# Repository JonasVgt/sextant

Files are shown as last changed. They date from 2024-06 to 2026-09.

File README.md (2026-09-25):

# 3D-Printed Sextant

## What is a sextant?
A sextant is a navigational instrument used for measuring
the angular distances between two objects, such as the 
horizon and a celestial body like the sun or a star. Using
these angles, navigators can determine their latitude 
and longitude. The accuracy and portability of the sextant
made it an essential tool for ocean navigation in the age of 
sail. Nowadays sextants are mostly used by hobbyists and as
a reliable backup to modern GPS technology.

## This Project

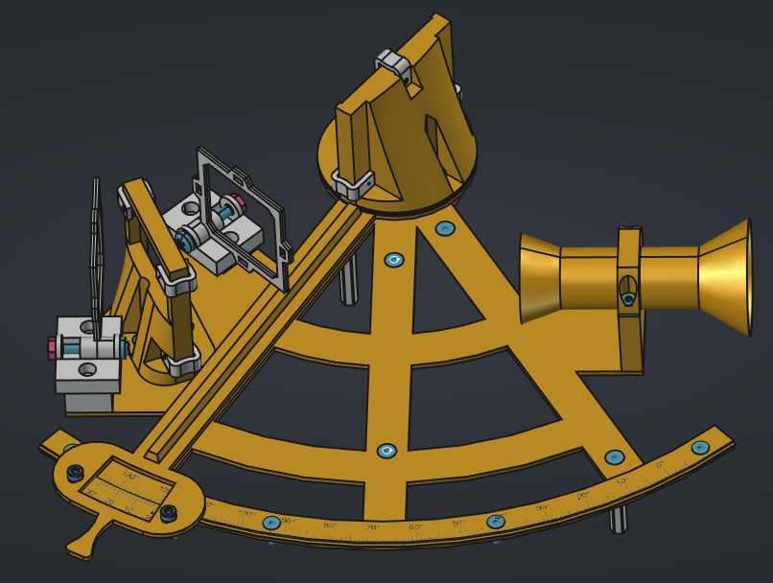
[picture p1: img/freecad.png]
FreeCAD preview of the sextant


After being caught in a rabbit hole of astronavigation, I 
wanted to experiment with navigation using sextants. 
Unfortunately, I quickly found  out that these devices are 
really expensive, and I didn't want to spend hundreds of 
dollars on my first sextant. That is why I decided to build 
my own, using 3D printing technology. The main focus of this 
project is to create a very cheap sextant that can be used 
by everyone who wants to experiment with astronavigation. I 
will try to make the device as accurate as possible, with a 
theoretical accuracy of around 1/6th of a degree or 10 nautical 
miles. For more accurate measurements, different techniques 
and materials are probably needed. The design will be 
modular, so everyone can change it to fit their needs.

## Building your own
### What do you need?
You will need the following materials:

| Amount | Description |
| - | - |
| 10 | M3x10 Bolt (flat head) |
| 3 | M3x8 Bolt (countersunk head) |
| 6 | M3x10 Bolt (countersunk head) |
| 15 | M3 Hex Nut |
| 1 | M3x16 Bolt (countersunk head) |
| 2 | M4x20 Bolt (flat head) |
| 2 | M4 Hex Nut |
| 4 | M3x5 Bolt (countersunk) |
| 4 | M3x35 Hex standoff |
| 2 | Mirror 50x40x3mm |
| 1 | 608-ZZ Ball Bearing |
|  | Filament |

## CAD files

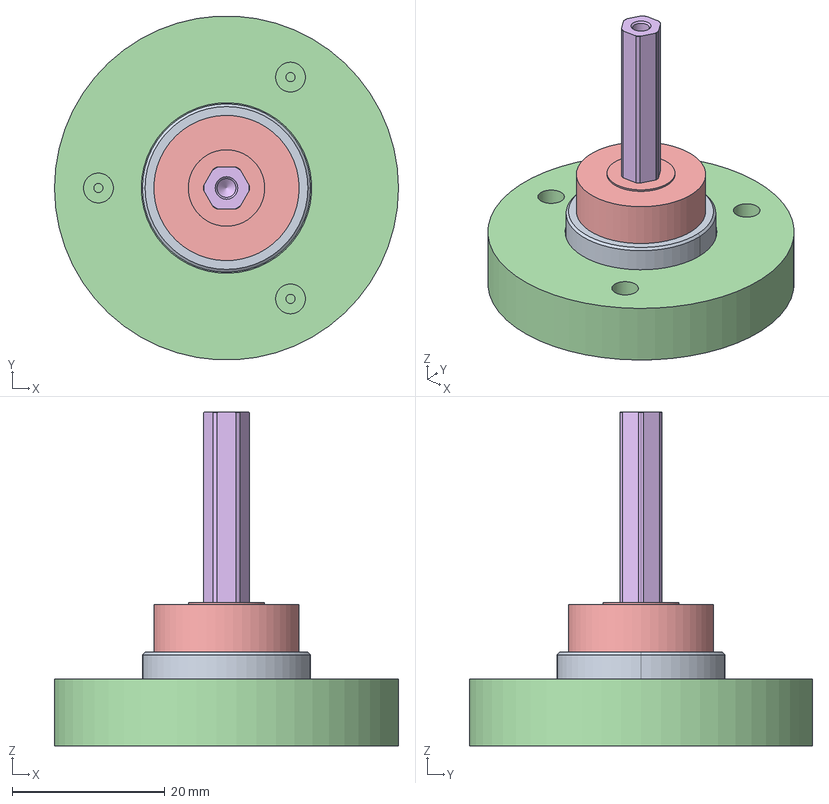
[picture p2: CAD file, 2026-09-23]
FreeCAD/Parts.FCStd
45.0 x 44.9 x 43.7 mm
6661K82_Ball Bearing
6661K82_Ball Bearing001
6661K82_Ball Bearing002
6661K82_Ball Bearing003
6661K82_Ball Bearing004
6661K82_Ball Bearing005
6661K82_Ball Bearing006
6661K82_Ball Bearing007
6661K82_Ball Bearing008
6661K82_Ball Bearing009
6661K82_Ball Bearing010
6661K82_Ball Bearing011
6661K82_Ball Bearing012
6661K82_Ball Bearing013
6661K82_Ball Bearing014
6661K82_Ball Bearing015
6661K82_Ball Bearing016
6661K82_Ball Bearing017
MirrorClipBody
BearingHousingBody
M3x35x5.5-Spacer

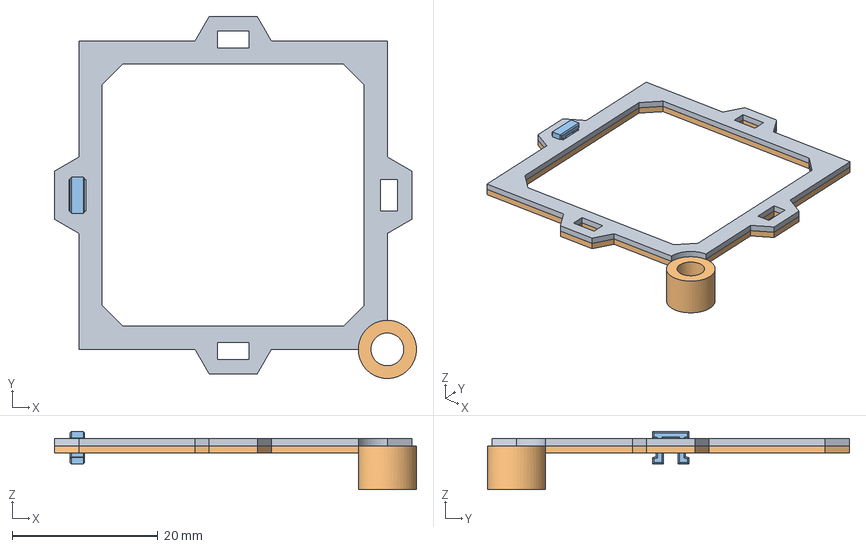
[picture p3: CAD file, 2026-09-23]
FreeCAD/Shade.FCStd
49.7 x 49.7 x 8.00 mm
ShadeFrameTop
ShadeFrameBottom
Clip

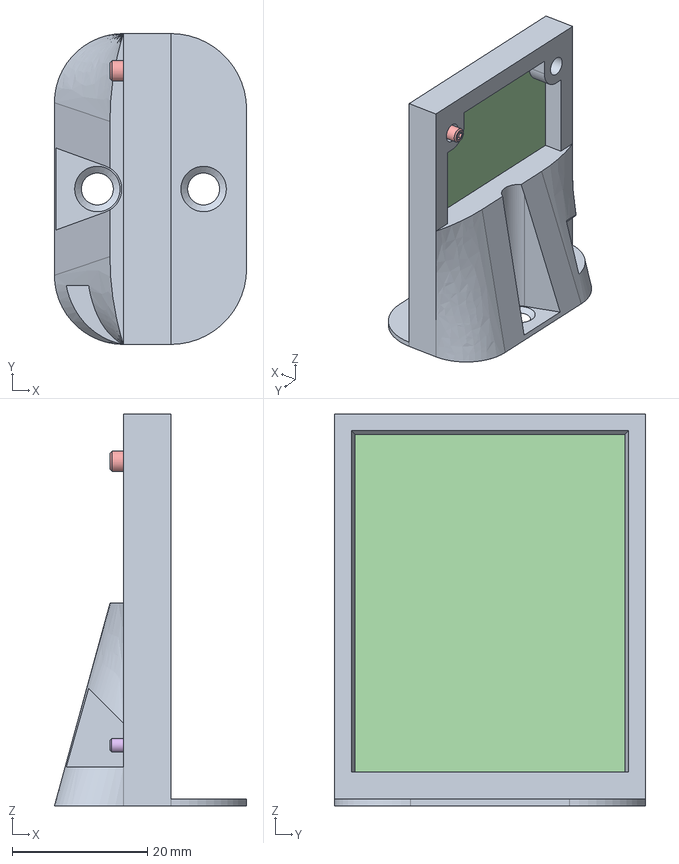
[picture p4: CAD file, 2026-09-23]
FreeCAD/HorizonMirror.FCStd
28.4 x 46.0 x 58.0 mm
HorizonMirrorFrameBody
Binder
M3x4-Screw
M2x4-Screw

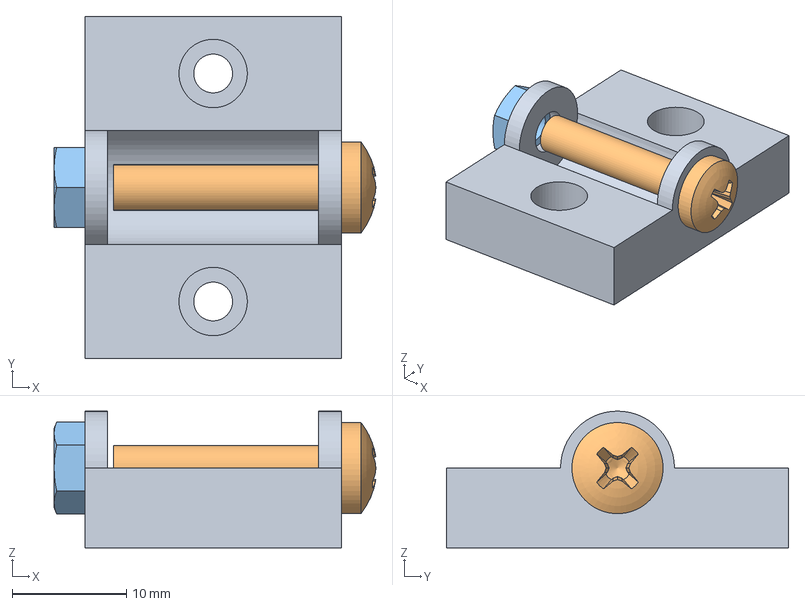
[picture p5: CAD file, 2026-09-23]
FreeCAD/Shadeset.FCStd
28.2 x 30.0 x 12.0 mm
Attachment
M4x20-Screw
M4-Nut

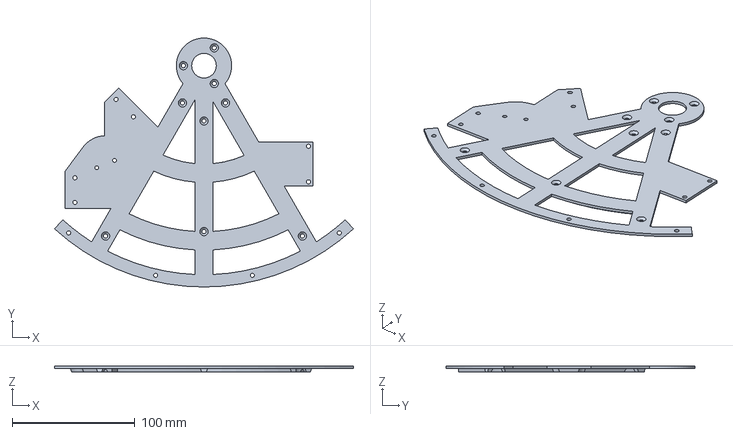
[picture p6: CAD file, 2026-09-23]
FreeCAD/Frame.FCStd
243.2 x 202.5 x 5.00 mm

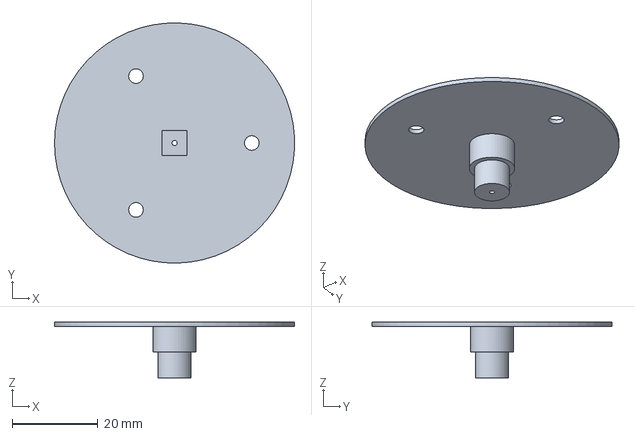
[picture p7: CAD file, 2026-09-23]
FreeCAD/Shaft.FCStd
56.0 x 56.0 x 13.0 mm

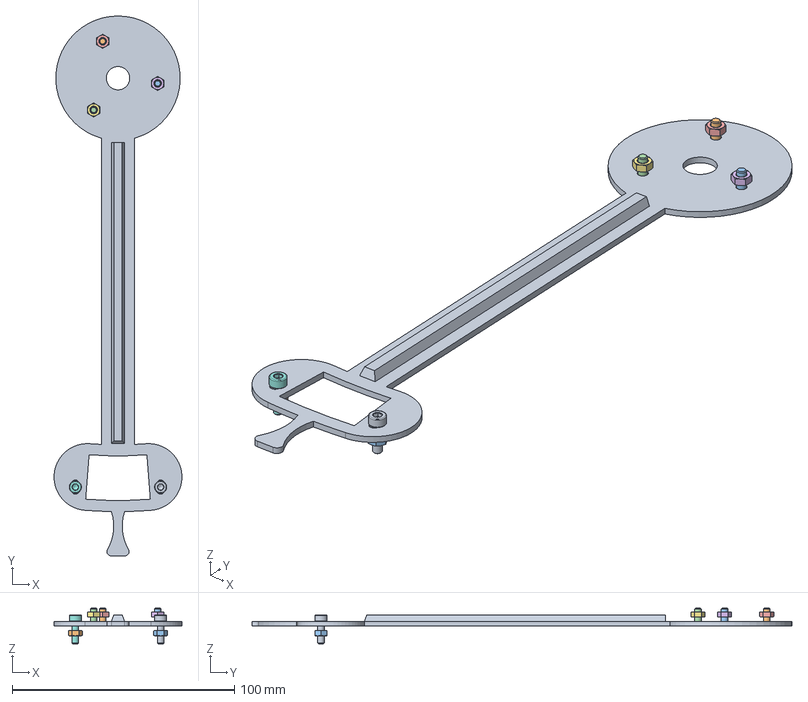
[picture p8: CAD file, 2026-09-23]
FreeCAD/IndexArm.FCStd
57.6 x 243.0 x 16.0 mm
IndexArm
M3x8-Screw
M3x8-Screw655
M3x8-Screw656
M3-Nut1361
M3-Nut
M3-Nut1362
M3x10-Screw001
M3x10-Screw
M3-Nut1363
M3-Nut1364

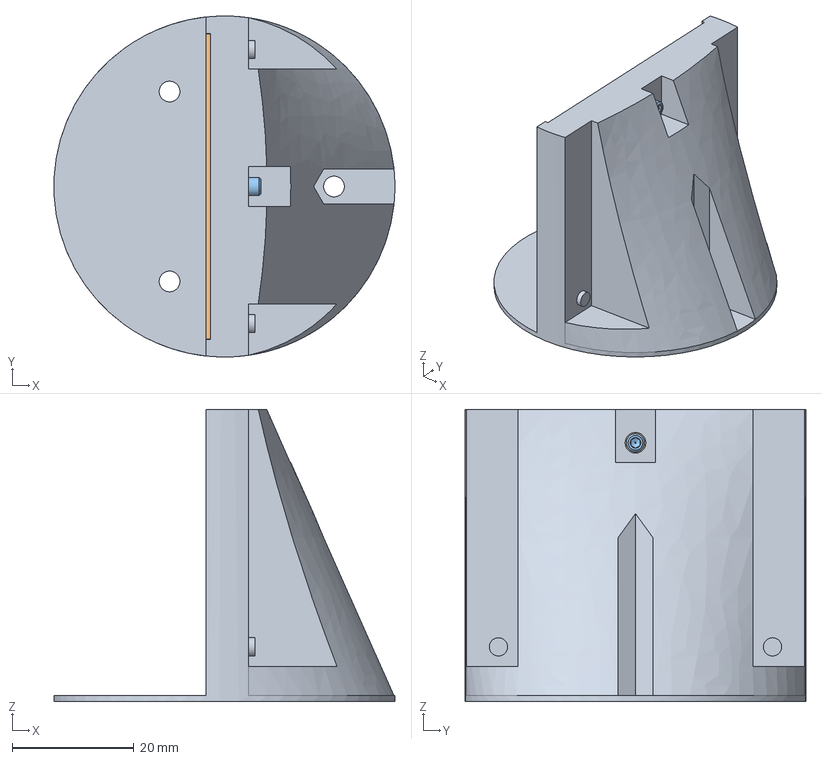
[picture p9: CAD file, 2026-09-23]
FreeCAD/IndexMirror.FCStd
56.0 x 56.0 x 48.0 mm
IndexMirrorFrameBody
M3x4-Screw

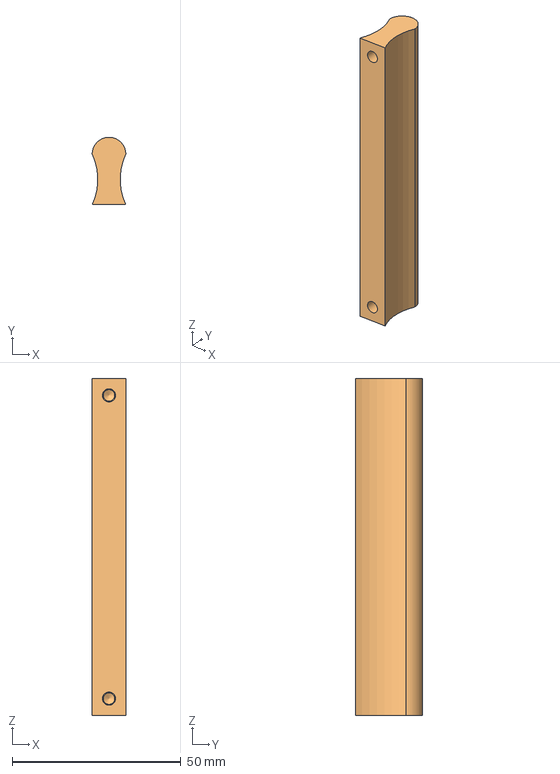
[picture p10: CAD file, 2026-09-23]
FreeCAD/Handle.FCStd
10.0 x 20.0 x 100.0 mm
Handle
Handle_ThreadedInsert

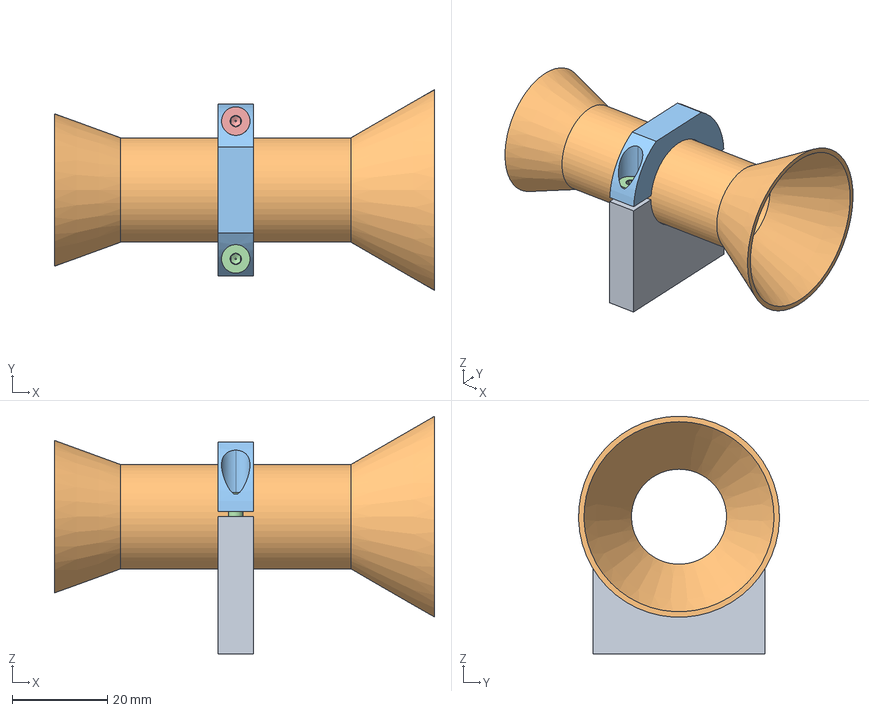
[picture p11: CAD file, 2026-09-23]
FreeCAD/Viewscope.FCStd
80.0 x 42.3 x 50.0 mm
CollarBottomBody
M3x10-Screw001
M3x10-Screw

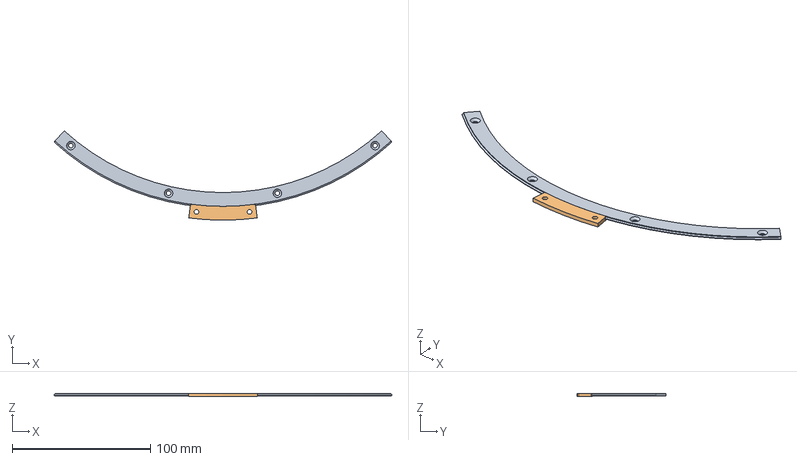
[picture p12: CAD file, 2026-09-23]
FreeCAD/Scale.FCStd
244.6 x 64.7 x 2.50 mm
MainScaleBody
VernierScaleBody

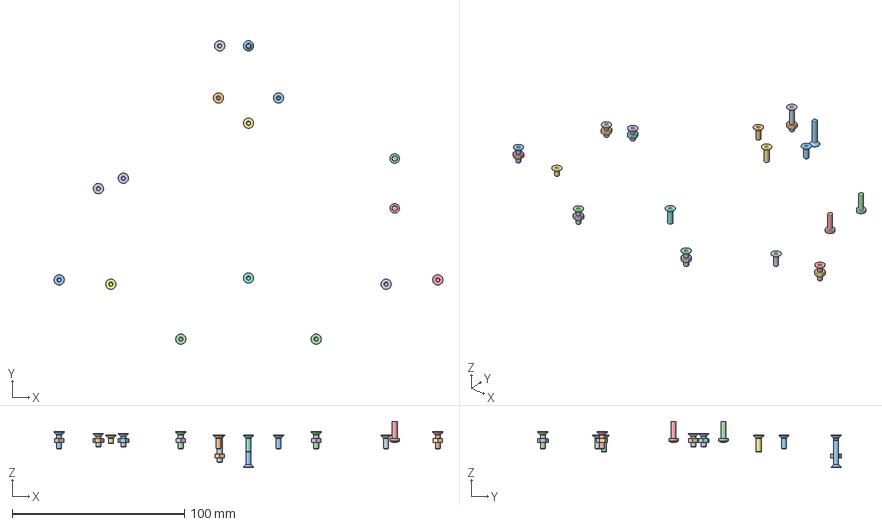
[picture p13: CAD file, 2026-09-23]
FreeCAD/Sextant.FCStd
226.1 x 176.9 x 27.0 mm
M3x16-Screw x 2
M3-Nut669 x 2
M3x10-Screw092 x 2
M3x10-Screw093 x 2
M3-Nut x 2
M3-Nut670 x 2
M3x10-Screw x 2
M3x10-Screw094 x 2
M3x8-Screw x 2
M3-Nut671 x 2
M3x16-Screw002 x 2
M3x10-Screw095 x 2
M3x10-Screw096 x 2
M3x8-Screw397 x 2
M3x5-Screw x 2
M3-Nut672 x 2
M3x8-Screw398 x 2
M3x8-Screw399 x 2
M3x8-Screw400 x 2
M3x10-Screw097 x 2
M3x10-Screw098 x 2
M3-Nut673 x 2
M3-Nut674 x 2

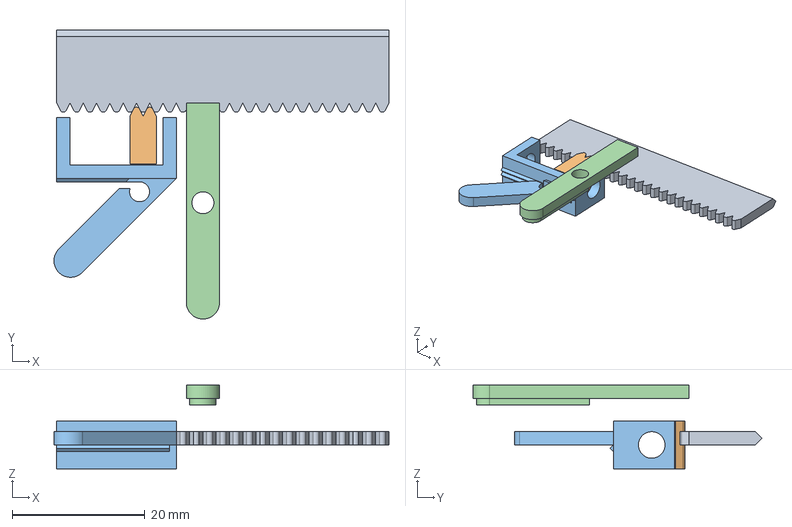
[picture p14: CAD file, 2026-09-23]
FreeCAD/ToothTest.FCStd
50.4 x 43.5 x 12.6 mm
Gears

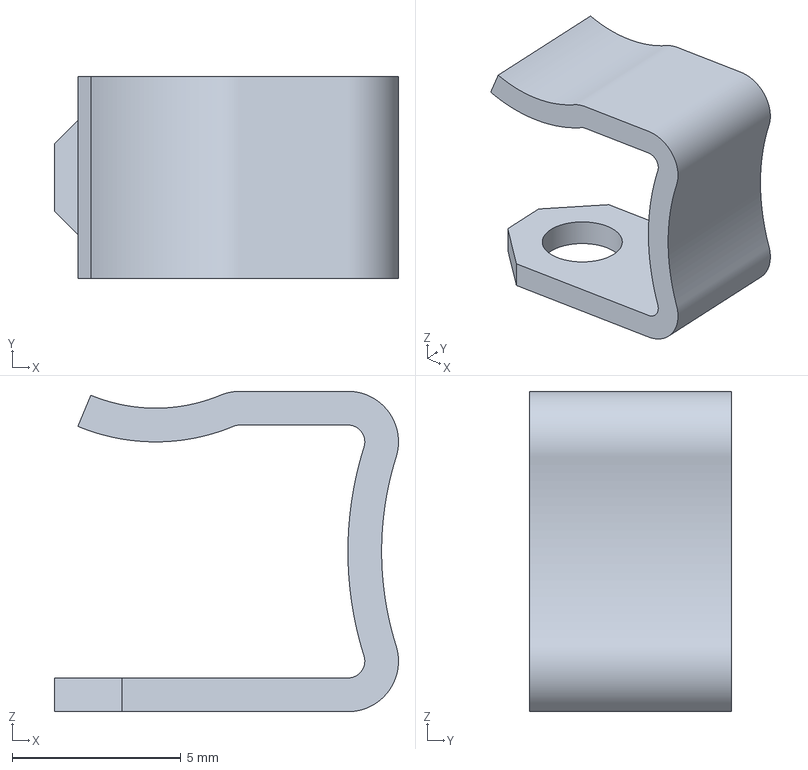
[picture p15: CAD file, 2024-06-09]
FreeCAD/Parts-MirrorClip.3mf
10.2 x 6.00 x 9.50 mm

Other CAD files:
FreeCAD/Resources.FCStd
FreeCAD/Viewscope-CollarTop.3mf
FreeCAD/Viewscope-CollarBottom.3mf
FreeCAD/Handle_CollarTop.3mf
FreeCAD/Frame.3mf
FreeCAD/Handle.3mf
FreeCAD/Handle_CollarBot.3mf

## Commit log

2024-05-11 add first version of model
    [Frame.FCStd, Handle.FCStd, HorizonMirror.FCStd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]
2024-05-13 fix index mirror thickness
    [IndexArm.FCStd, IndexMirror.FCStd, Parts.FCStd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]
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2024-05-13 make horizon mirror better printable
    [Handle.FCStd, HorizonMirror.FCStd, IndexArm.FCStd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]
2024-05-13 remove overhang from horizon mirror
    [Frame.FCStd, HorizonMirror.FCStd, Parts.FCStd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]
2024-05-13 round back of horizon mirror
    [Frame.FCStd, HorizonMirror.FCStd, Sextant.FCStd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]
2024-05-13 changed location of viewscope
    [Frame.FCStd, HorizonMirror.FCStd, Sextant.FCStd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]
2024-05-14 add new fill to frame
    [Frame.FCStd, Handle.FCStd, IndexArm.FCStd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]
2024-05-14 change shape of horizon mirror base
    [Frame.FCStd, Handle.FCStd, HorizonMirror.FCStd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]
2024-05-14 add handle to index arm
    [Frame.FCStd, HorizonMirror.FCStd, IndexArm.FCStd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]
2024-05-14 add datum planes to index arm
    [IndexArm.FCStd, Parts.FCStd, Resources.FCStd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]
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2024-05-19 add filterset to for index mirror
    [Filter.FCStd, Filterset.FCStd, Frame.FCStd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]
2024-05-19 add filterset to horizon mirror
    [Filter.FCStd, Filterset.FCStd, Frame.FCStd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]
2024-05-19 add base model for filter frame
    [Filter.FCStd, Filterset.FCStd, Frame.FCStd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]
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2024-05-19 update shape of filter frame
    [Filter.FCStd, Filterset.FCStd, Frame.FCStd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]
2024-05-19 update position of filtersets
    [Frame.FCStd, HorizonMirror.FCStd, Sextant.FCStd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]
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2024-06-05 make top collar for viewscope better printable
    [Sextant.FCStd, Viewscope.FCStd]
2024-06-05 add threaded insert version for handle
    [Filterset.FCStd, Frame.FCStd, Handle.FCStd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]
2024-06-05 reduced scale radius to 180mm
    [Filterset.FCStd, Frame.3mf, Frame.FCStd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]
2024-06-05 increased bearing housing diameter to 45mm
    [Filterset.FCStd, Frame.3mf, Frame.FCStd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]
2024-06-06 increased mirror thickness to 3mm
    [Filter.FCStd, HorizonMirror.FCStd, IndexArm.FCStd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]
2024-06-06 adjusted mirror clip for M3 adjustment screws
    [Filter.FCStd, HorizonMirror.FCStd, IndexArm.FCStd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]
2024-06-06 increased gap of viewscope collar by 1mm
    [Filter.FCStd, HorizonMirror.FCStd, IndexArm.FCStd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]
2024-06-06 added slots for threaded inserts to viewscope collar
    [Filter.FCStd, HorizonMirror.FCStd, IndexArm.FCStd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]
2024-06-07 increased horizon mirror size
    [Filter.FCStd, Filterset.FCStd, Frame.FCStd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]
2024-06-07 updated horizon mirror to have rounded edges
    [Frame.FCStd, HorizonMirror.FCStd, Parts.FCStd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]
2024-06-07 adjusted shaft for 3d printing, added threaded insert hole
    [HorizonMirror.FCStd, Parts.FCStd, Resources.FCStd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]
2024-06-07 adapted bearing housing for 3d printing, added threaded insert holes
    [HorizonMirror.FCStd, Parts.FCStd, Resources.FCStd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]
2024-06-08 adjusted horizon mirror for 3d printing, added threaded insert holes
    [Filter.FCStd, Filterset.FCStd, Frame.FCStd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]
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2024-06-08 make mirror clip have correct dimensions
    [HorizonMirror.FCStd, Parts.FCStd, Resources.FCStd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]
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2024-06-09 various adjustments to index arm
    [Filter.FCStd, Filterset.FCStd, Frame.FCStd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]
2024-06-09 adjusted bearing housing, decreased gap between bearing housing and frame, reduced clearance loose fit to 0.15mm to make bearing better fit in housing
    [Filter.FCStd, Filterset.FCStd, Frame.FCStd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]
2024-07-21 correct filter clip dimensions
    [Filter.FCStd, Filterset.FCStd, Handle.FCStd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]
2024-07-21 make shade clip larger
    [Parts.FCStd, Resources.FCStd, Sextant.FCStd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]
2024-07-21 reduce amounts of shades to 2
    [Parts.FCStd, Resources.FCStd, Sextant.FCStd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]
2024-07-21 move viewscope and horizon mirror
    [Frame.FCStd, Parts.FCStd, Resources.FCStd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]
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2024-07-22 update frame for new shade set
    [Frame.FCStd, HorizonMirror.FCStd, IndexArm.FCStd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]
2024-07-22 add support blocks for shades
    [Frame.FCStd, Handle.FCStd, HorizonMirror.FCStd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]
2024-07-22 change orientation of attachment screws for shades
    [Frame.FCStd, Handle.FCStd, HorizonMirror.FCStd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]
2024-07-22 fixed wrong offset for horizon shade
    [Frame.FCStd, HorizonMirror.FCStd, Sextant.FCStd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]
2024-07-24 add stencil for shades
    [Frame.FCStd, HorizonMirror.FCStd, Parts.FCStd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]
2024-07-24 add extra holes for scale
    [Frame.FCStd, Scale.FCStd, Sextant.FCStd]
2024-07-24 add additional radial support to frame
    [Frame.FCStd, IndexArm.FCStd, Parts.FCStd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]
2024-07-24 add additional support around the ring
    [Frame.FCStd, IndexArm.FCStd, Parts.FCStd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]
2024-07-24 add holes for standoffs into frame
    [Frame.FCStd, Sextant.FCStd]
2024-07-24 add extra support all around the frame
    [Frame.FCStd, IndexArm.FCStd, Parts.FCStd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]
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2024-07-25 make bearing end_cover 10mm long to accomodate longer screw
    [Handle.FCStd, HorizonMirror.FCStd, IndexArm.FCStd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]
2024-07-26 add standoffs for sextant to lay on
    [Frame.FCStd, Handle.FCStd, HorizonMirror.FCStd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]
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2024-07-26 update attachment of viewscope to reflect actual attachment
    [Frame.FCStd, Parts.FCStd, Resources.FCStd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]
2024-07-26 add grove to vernier scale to interface with main scale
    [Frame.FCStd, Parts.FCStd, Resources.FCStd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]
2024-07-27 make vernier scale taller to prevent it slipping out of the guiderail
    [Frame.FCStd, IndexArm.FCStd, Parts.FCStd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]
2024-07-27 update position and type of screws holding vernier scale
    [Frame.FCStd, IndexArm.FCStd, Parts.FCStd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]
2024-07-27 fix standoffs orientation
    [Frame.FCStd, IndexArm.FCStd, Parts.FCStd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]
2024-07-27 add additional screws for main scale
    [Frame.FCStd, IndexArm.FCStd, Parts.FCStd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]
2024-07-27 change shade frame to better hold the shade
    [Frame.FCStd, IndexArm.FCStd, Parts.FCStd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]
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2024-07-27 reduced size of clips to make shades fit closer together
    [Frame.FCStd, IndexArm.FCStd, Parts.FCStd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]
2024-07-28 update shadeset to have automatically use right amount of shades
    [Frame.FCStd, Handle.FCStd, HorizonMirror.FCStd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]
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
